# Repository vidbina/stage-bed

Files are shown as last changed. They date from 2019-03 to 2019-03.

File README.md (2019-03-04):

# Stage Bed :metal:

<br />This work is licensed under a <a rel="license" href="http://creativecommons.org/licenses/by/4.0/">Creative Commons Attribution 4.0 International License</a>.

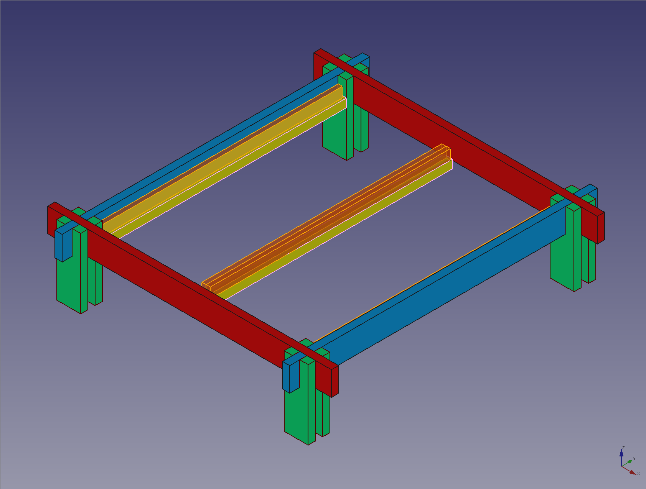
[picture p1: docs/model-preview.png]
Preview of the bed model when composed


This is a frame for the bed that [Leni][leni] and I designed and built with the
help of [Clément][clement] who you should hire if you need any dope stuff built
in Berlin :bear: :de:. The panelling work is not included in these drafts. The
design objective was to create a bed that could double as a set for photoshoots
or a stage for pillow fights or bedroom concerts :sunglasses:. Leni just walked
into the cafe where I'm publishing this and the first thing she mentioned is
how she can store her entire life beneath the mattress so yeah... I guess it
serves a pretty niftly storage unit as well. We built a version with slightly
higher pillars and I guess a great percentage of humans can sit upright or
comfortably crawl under the mattress.

Here is a picture of Leni posing on a version of the bed. I have to credit
Clément for the build quality and stellar paint-job.

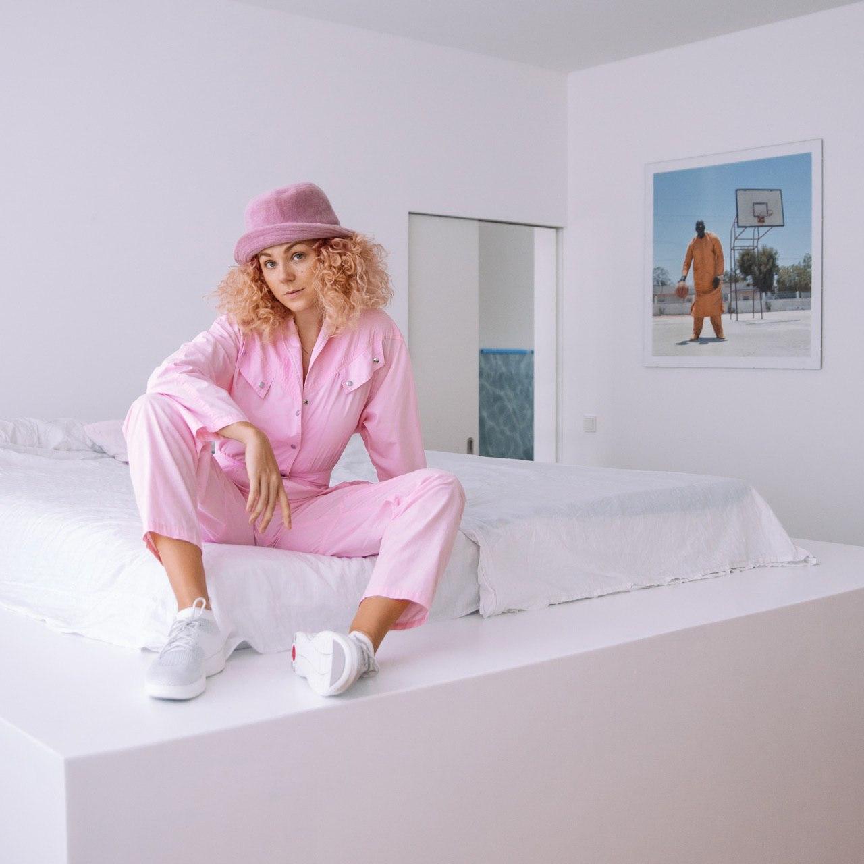
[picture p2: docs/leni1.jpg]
Leni sitting on the bed with a decent view of the seating area around the mattress


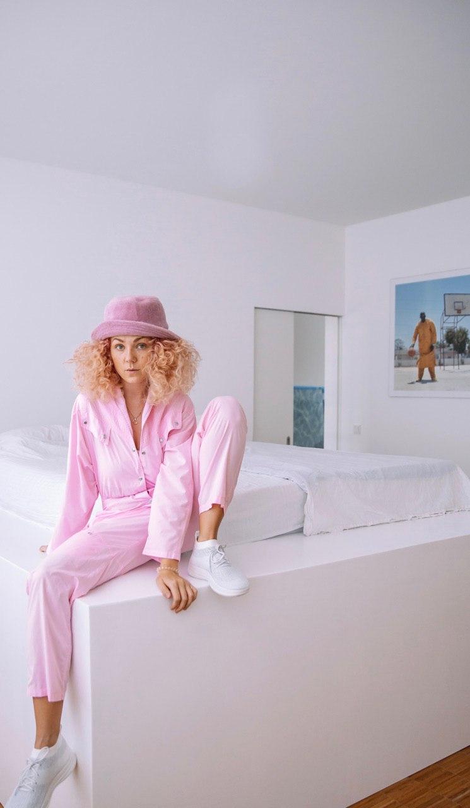
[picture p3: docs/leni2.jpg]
Leni sitting on the bed with the floor visible such that it is possible to see how tall the bed approximately is (half as tall as Leni at least)


A [plan][plan] of the components required is provided in [docs/plan.pdf][plan]

## Parameters

The model has been parameterized to allow the changing of the dimensions of the
model by simply altering the values in the Dimensions table within the FreeCAD
project.

> Some components may require repositioning if values in this table are
> modified.

| Section | Dimension | Description |
|----|----|----|
| `Mattress` | `length` | Length of the mattress|
| `Mattress` | `width` | Width of the mattress|
| `Mattress` | `height` | Height of the mattress|
| `Mattress` | `radius` | Radius in the rounding of the mattress corners|
| `Slat supports` | `Slat width` | Width of one the edge slat of the Lattenrost | 
| `Slat supports` | `Slat height` | Height of the one edge slat of the Lattenrost |
| `Slat supports` | `slat_foundation_side` | Width of the support that carries the slats of the Lattenrost |
| `Beams` | `width` | Width of the beams used to create the top-facing support lattice |
| `Beams` | `height` | Height of the beams used to create the top-facing support lattice |
| `Beams` | `groove` | Height of the groove used to interlock the beams in the top-facing support lattice |
| `Loadbearer` | `length` | Length of the beams used for top-facing surface |
| `Loadbearer` | `height` | Height of the beams used for the top-facing surface (same as `Beams` / `height`) |
| `Loadbearer` | `width` | Width of the beams used for the top-facing surface (same as `Beams` / `width`) |
| `Pillars` | `height` | I dunno :expressionless: |
| | `seat_height` | The height of the sitting surface |
| | `seat_width` | The width of the sitting edge around the mattress |

[plan]: ./docs/plan.pdf
[leni]: https://instagram.com/lenipaperboats
[clement]: https://instagram.com/clecledontplayplay

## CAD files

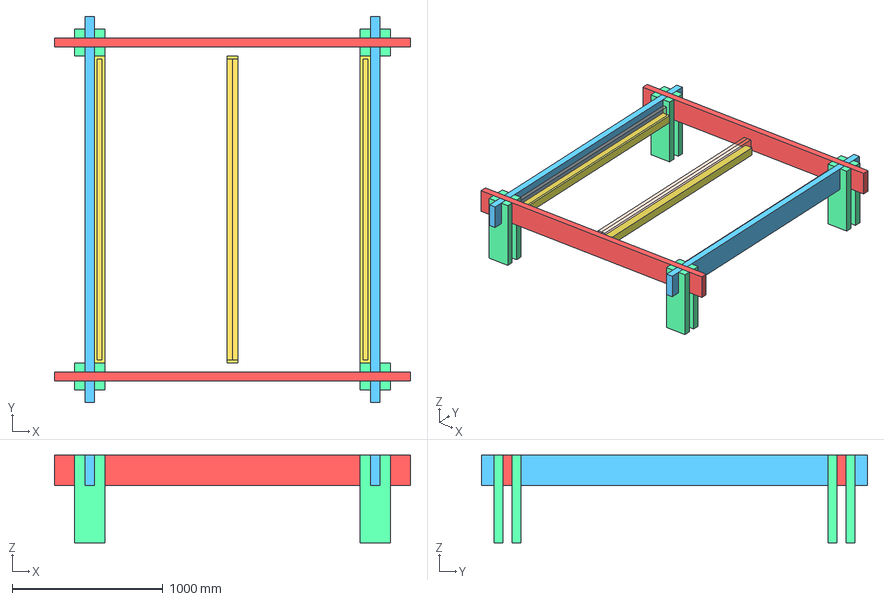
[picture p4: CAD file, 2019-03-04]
alpha.FCStd
2364.0 x 2564.0 x 582.0 mm
Right
Left
Rightmost
Leftmost
Outer Top Right Main Pillar
Inner Top Right Main Pillar
Inner Bottom Right Main Pillar
Outer Bottom Right Main Pillar
Outer Top Left Main Pillar
Inner Top Left Main Pillar
Inner Bottom Left Main Pillar
Outer Bottom Left Main Pillar
Left Long Beam
Right Long Beam
Head Long Beam
Foot Long Beam
Right Slat Foundation
Left Slat Foundation
Center Slat Foundation

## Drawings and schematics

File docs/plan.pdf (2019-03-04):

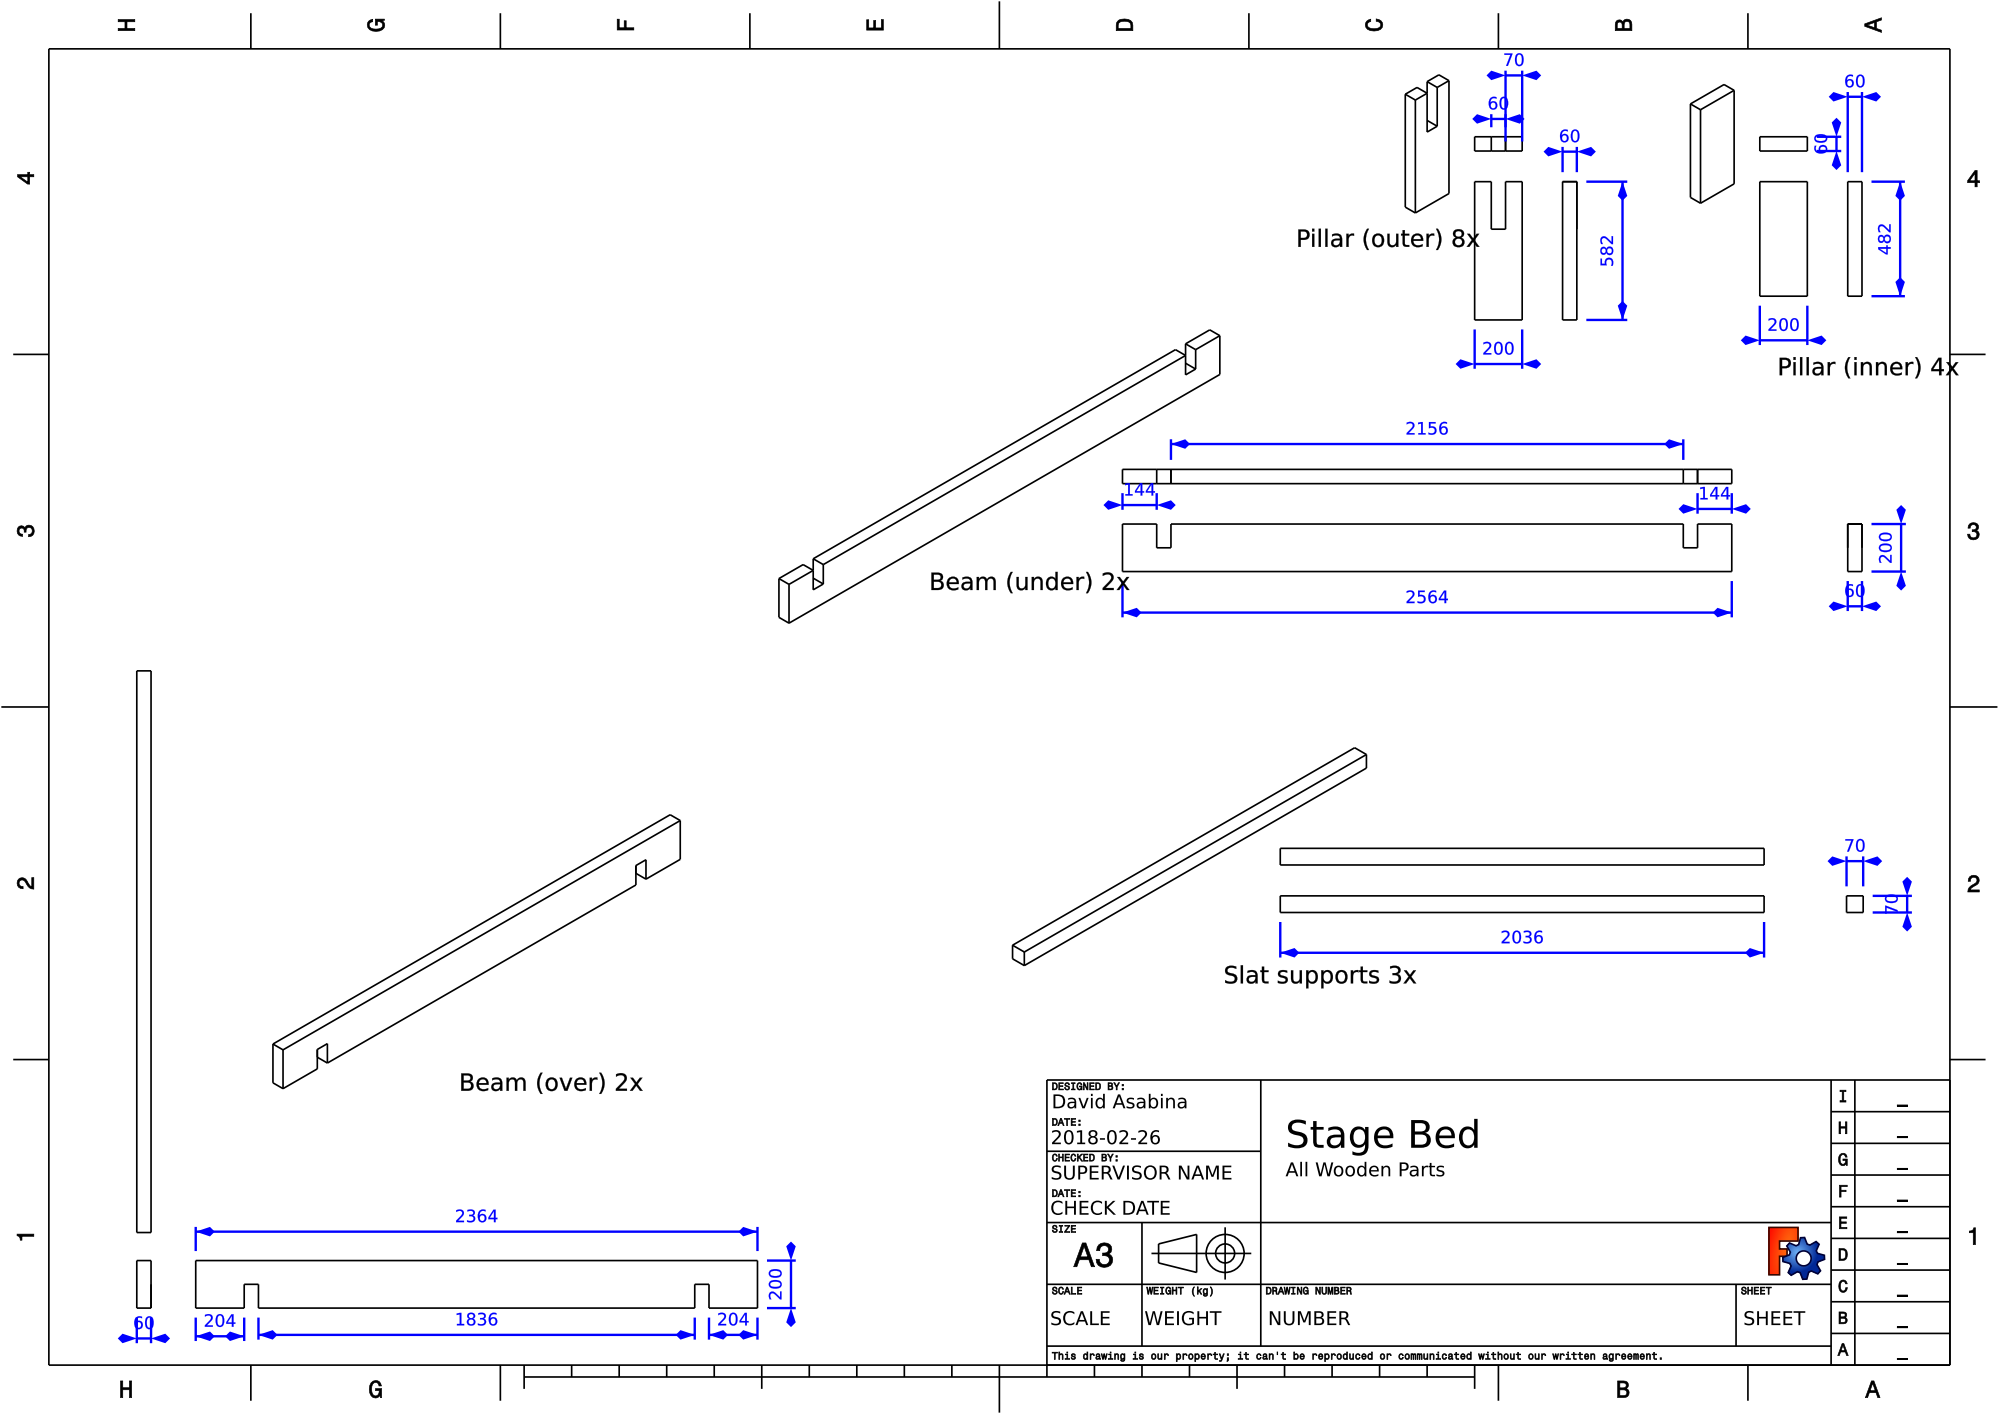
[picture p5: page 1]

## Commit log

2017-03-13 stable lattice frame
    [alpha.FCStd]
2017-03-14 setting up basic dimensions
    [alpha.FCStd]
2017-03-14 start of centering the design
    [alpha.FCStd]
2017-03-14 fully centered parametrized bearers
    [alpha.FCStd]
2017-03-14 centralized frames
    [alpha.FCStd]
2017-03-14 starting w/ surface bearers
    [alpha.FCStd]
2017-03-14 start with pillars
    [alpha.FCStd]
2017-03-14 all base pillars
    [alpha.FCStd]
2017-03-14 added corner pillars
    [alpha.FCStd]
2017-03-14 out of ideas for today... need to join the pillars to the exoframe
    [alpha.FCStd]
2017-03-15 suface beams
    [alpha.FCStd]
2017-03-17 inner main pillars
    [alpha.FCStd]
2017-03-17 legs to inside
    [alpha.FCStd]
2017-09-27 dynamic dimensions for Framed Corner Pillar Format
    [alpha.FCStd]
2017-09-27 added beam dimensions
    [alpha.FCStd]
2017-09-27 constrained the new pillar outline
    [alpha.FCStd]
2017-09-27 pillar height based on sitting height param
    [alpha.FCStd]
2017-09-27 nudged top beam
    [alpha.FCStd]
2017-09-27 designed a new horizontal beam
    [alpha.FCStd]
2017-09-27 just saving again… not too sure w/ these binaries
    [alpha.FCStd]
2017-09-28 updated x pos of pillars
    [alpha.FCStd]
2017-09-28 updated x-pos of pillars
    [alpha.FCStd]
2017-09-28 pos. left flat beam but prepping to repos. rest
    [alpha.FCStd]
2017-09-28 moved all pillars up to stand on the zero plane
    [alpha.FCStd]
2017-09-28 Dimensions statt Spreadsheet
    [alpha.FCStd]
2017-09-28 again
    Problem with these binaries is that it is hard to do diffs to see what
    actually changed.
    [alpha.FCStd]
2017-09-28 adding spacing for the surface box
    [alpha.FCStd]
2017-09-28 leaving room between pillars and surface panels
    [alpha.FCStd]
2017-09-28 bottom flat beams
    [alpha.FCStd]
2017-09-28 profile for top beam
    [alpha.FCStd]
2017-09-28 all top beams
    [alpha.FCStd]
2017-09-28 removing relics
    [alpha.FCStd]
2017-09-28 mattress height
    Somehow we have to figure out whether we can use wider boards, otherwise
    we risk having a large distance between the surface of the mattress and
    the sitting plane. This delta is far from ideal, as are larger boards.
    [alpha.FCStd]
2017-09-29 sideboards closer to mattress
    [alpha.FCStd]
2017-09-29 about to move mattress up
    [alpha.FCStd]
2017-09-29 set up slat foundations
    [alpha.FCStd]
2017-09-29 moved slat supports up
    [alpha.FCStd]
2017-09-29 moved everything in the right position
    [alpha.FCStd]
2017-09-29 60x200mm beams as found in Holz Possling
    Brettschichtholz Fichte 60x200mm - 4,00mtr.
    530378 (lfm)
    530380 (Stck)
    [alpha.FCStd]
2017-09-29 equalised seating area around edge of bed
    [alpha.FCStd]
2017-09-29 board to 18mm
    [alpha.FCStd]
2017-10-01 updating leg params
    [alpha.FCStd]
2017-10-02 reoriented one leg
    [alpha.FCStd]
2017-10-02 slats extended
    [alpha.FCStd]
2018-02-24 bed dimensions constrained to mattress+seat
    Instead of the weird dimensions, I've head before I've redefined the
    length and width to simply the matress dimensions plus the seat
    dimensions. I could have subtracted the panel thickness to actually
    constrict the entire design...
    [alpha.FCStd]
2018-02-25 added drawing w/ dimensions for bottom long beam
    [alpha.FCStd]
2018-02-25 subtracted surface thickness
    This should ensure that the dimensions of the bed are just the mattress
    dimensions with the seating dimensions.
    [alpha.FCStd]
2018-02-25 added top beam to page
    [alpha.FCStd]
2018-02-25 fighting with projections :rage:
    [alpha.FCStd]
2018-02-26 redid drawing
    Redoing the drawing without Drawing Dimensions. Getting weird errors and
    not sure how to solve them so I will add annotations to the PDF for the
    time being.
    [alpha.FCStd]
2018-02-26 reannotated model
    [alpha.FCStd]
2018-02-26 added part count in page
    [alpha.FCStd]
2018-02-26 uniform slat supports, but center pillar needed
    I've ensured that all slat supports (3) are the same, but as a result I
    will need a center pillar to support the center supports.
    [alpha.FCStd]
2018-02-26 made slat supports wider
    This should ensure maximum surface area for the inner edges of the
    Lattenrost whereas the outer edges of the Lattenrost will a greater
    tolerance for "shifting".
    [alpha.FCStd]
2019-03-04 Enable visibility of pillars and set perspective
    [alpha.FCStd]
